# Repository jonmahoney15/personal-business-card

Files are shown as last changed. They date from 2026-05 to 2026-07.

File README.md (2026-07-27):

# Personal Business Card

ESP32-C3 powered business card with a MAX7219 LED matrix displaying a Snake game.

## Firmware
The app is written in Rust. It makes use of `esp_hal` and the `MAX7219` crate.

The embassy framework is used as the runtime enabling async workflows.

## Hardware

| Component | Description |
|---|---|
| ESP32-C3 | Wi-Fi/BLE microcontroller running the firmware |
| MAX7219 | LED matrix driver IC |
| LED Matrix 8x8 | 64-LED display used for the Snake game |
| AMS1117 | 3.3V linear voltage regulator |
| USB-C | Power and programming interface |

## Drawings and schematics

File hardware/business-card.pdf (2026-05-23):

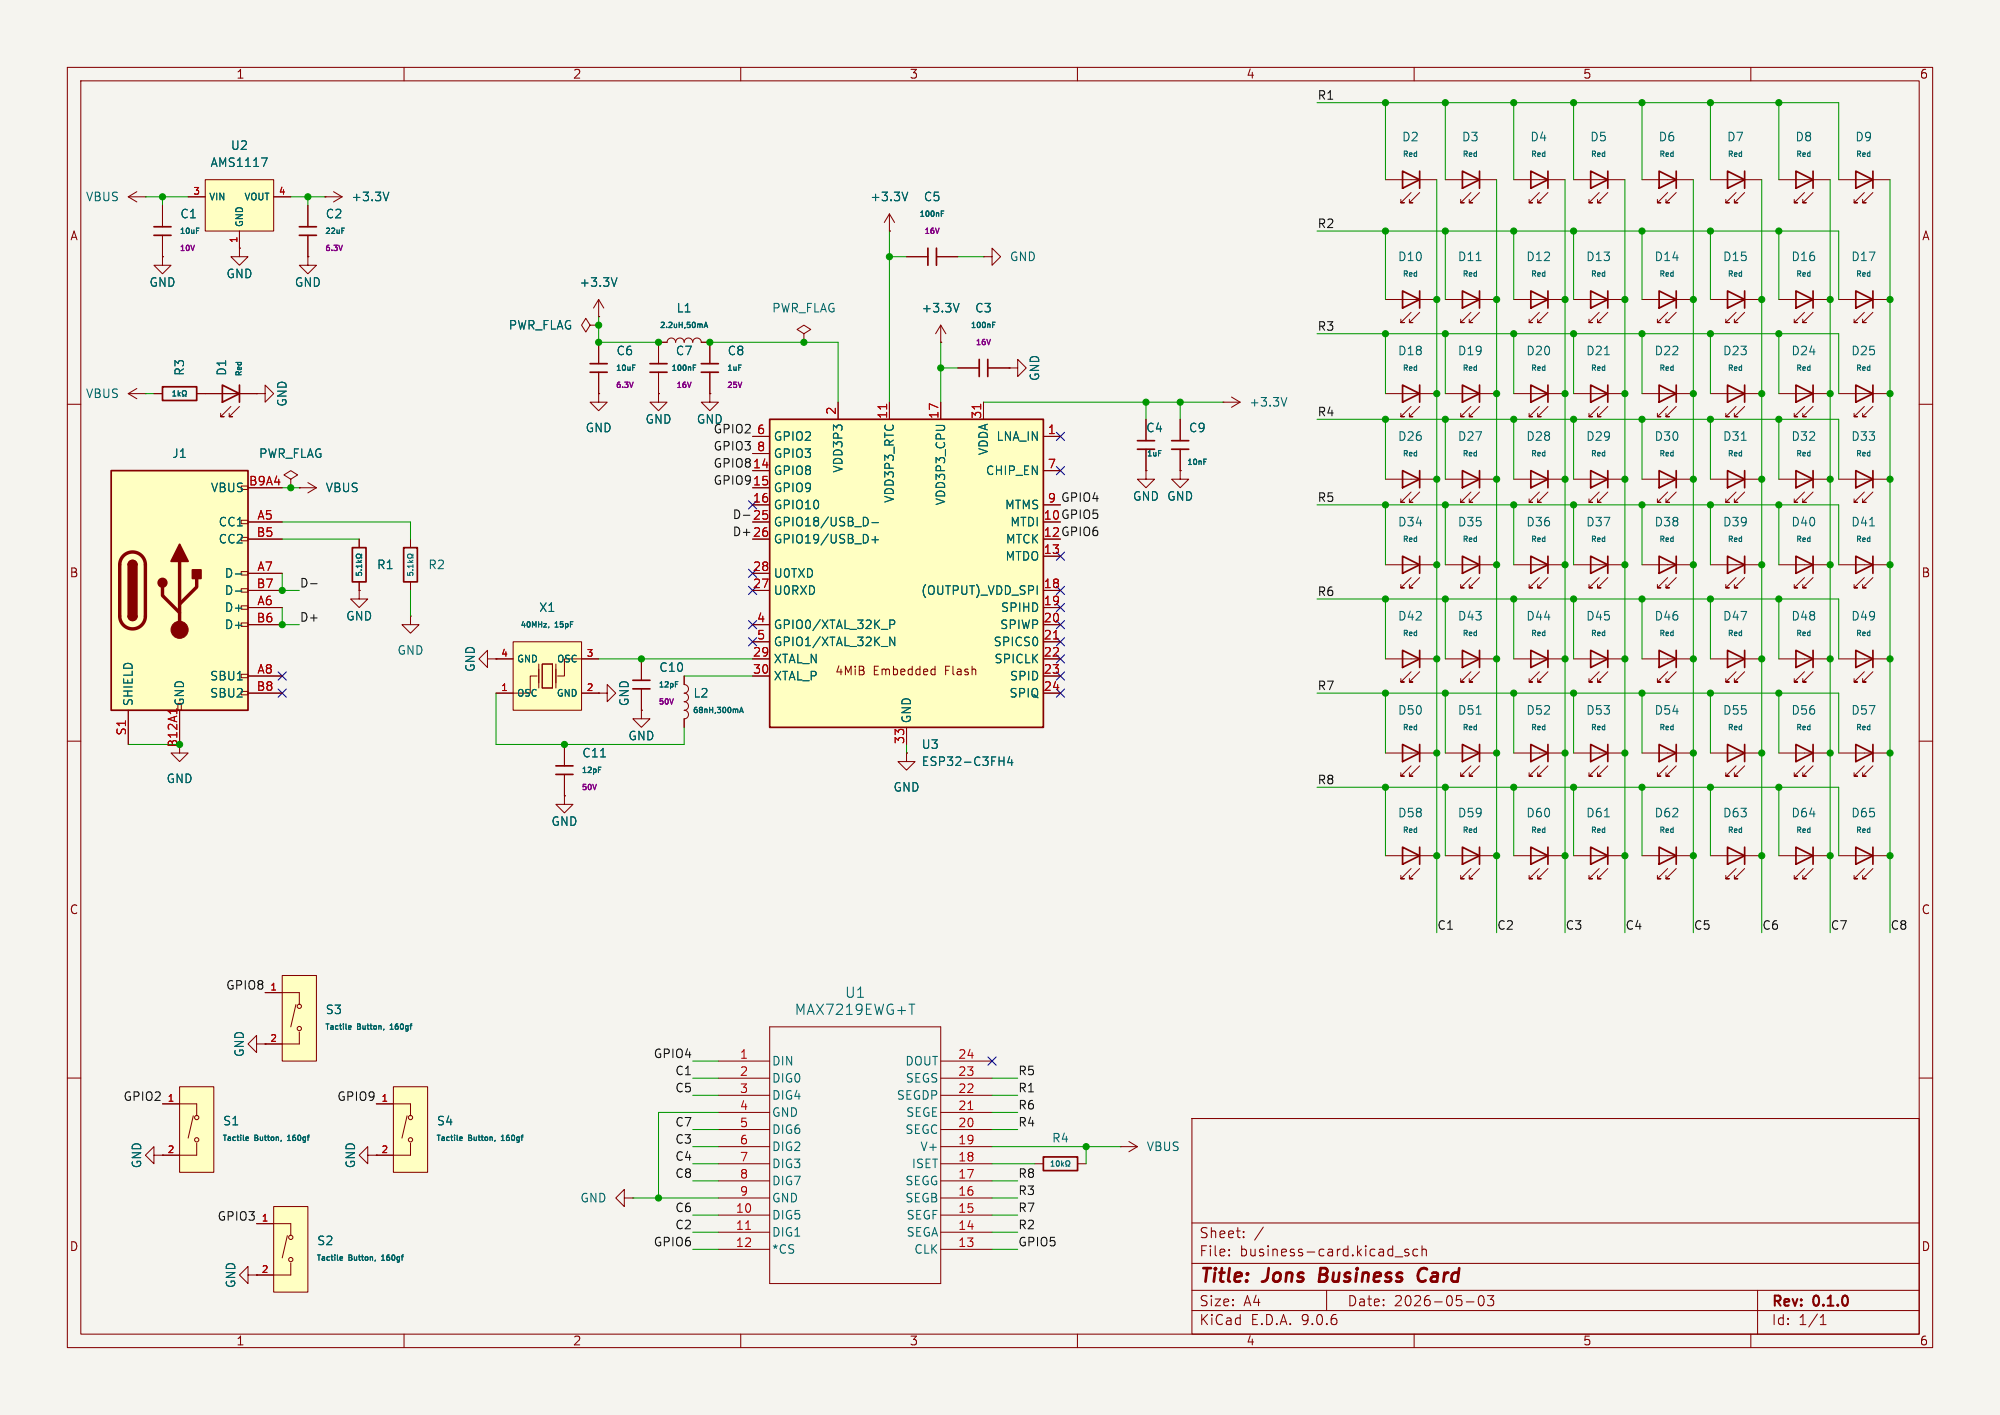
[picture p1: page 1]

Id: 1/1 Title: Jons Business Card

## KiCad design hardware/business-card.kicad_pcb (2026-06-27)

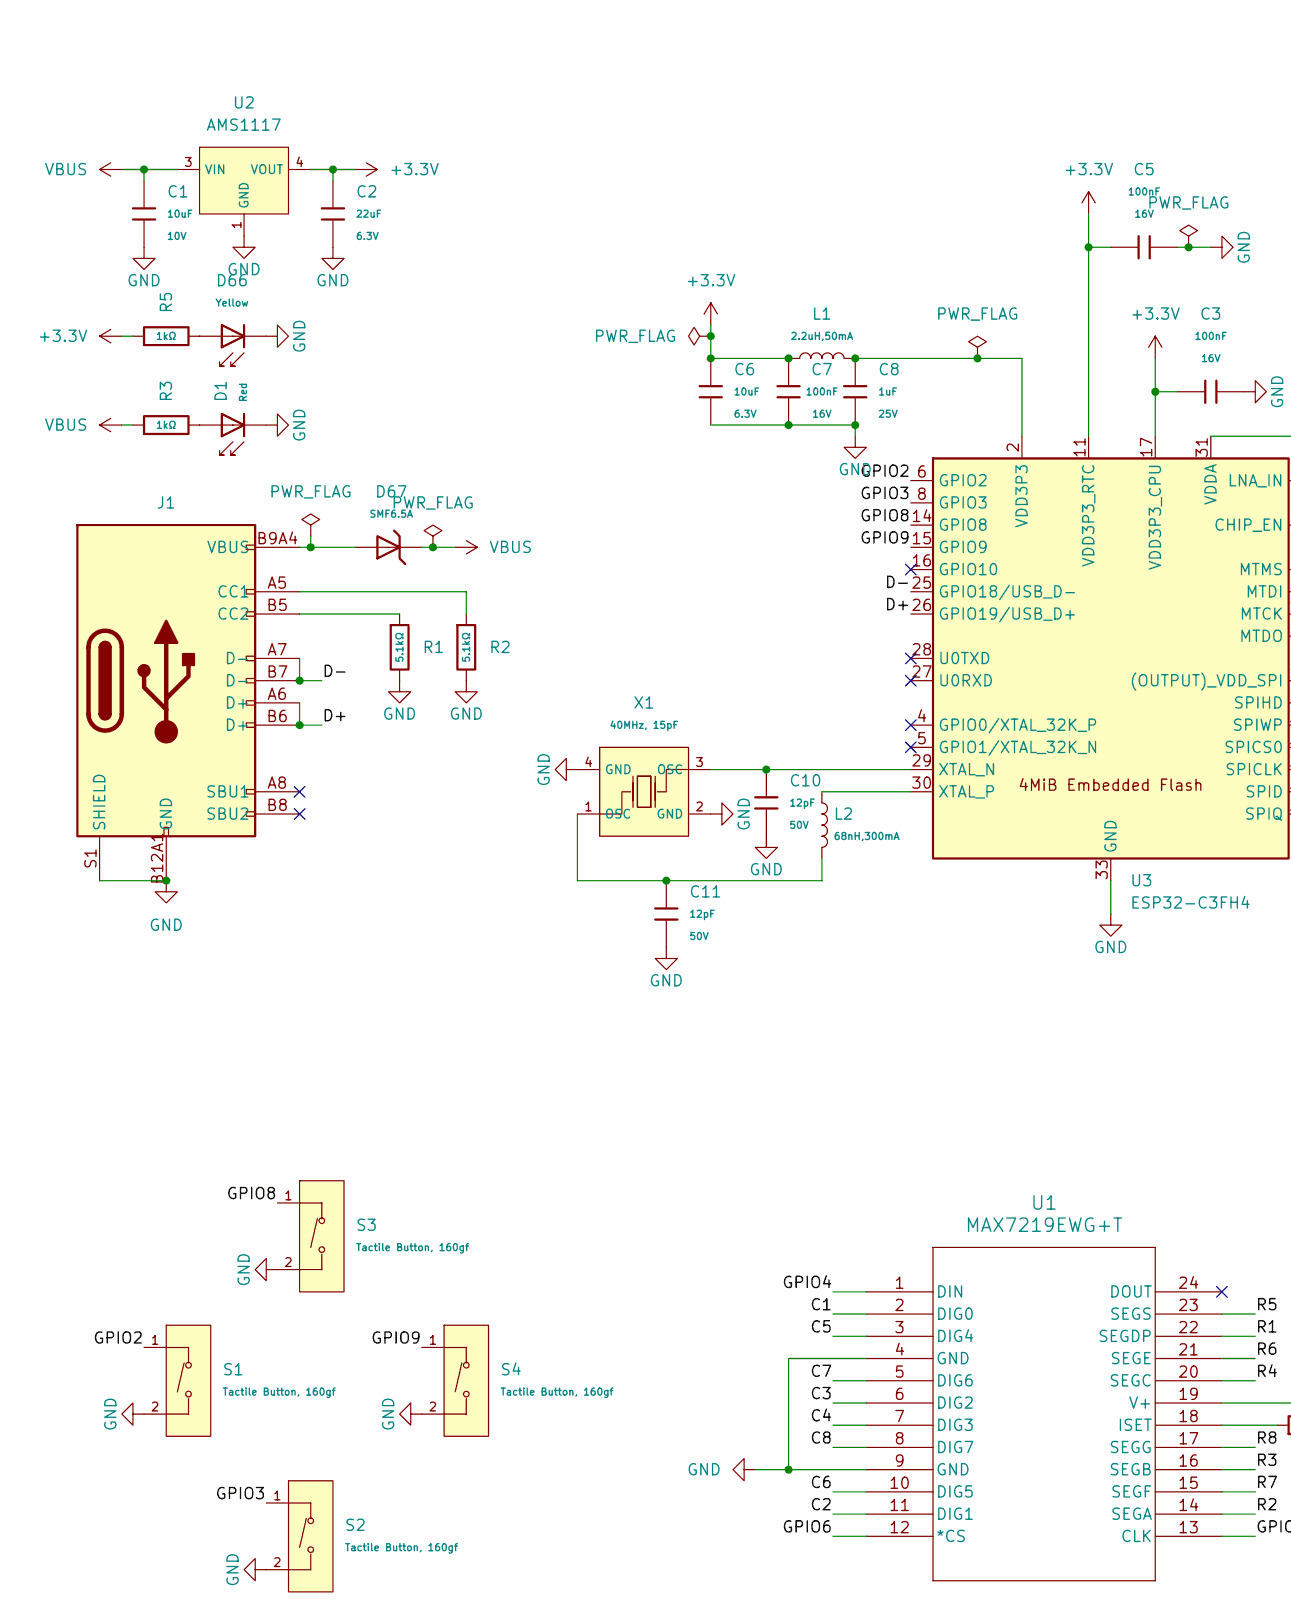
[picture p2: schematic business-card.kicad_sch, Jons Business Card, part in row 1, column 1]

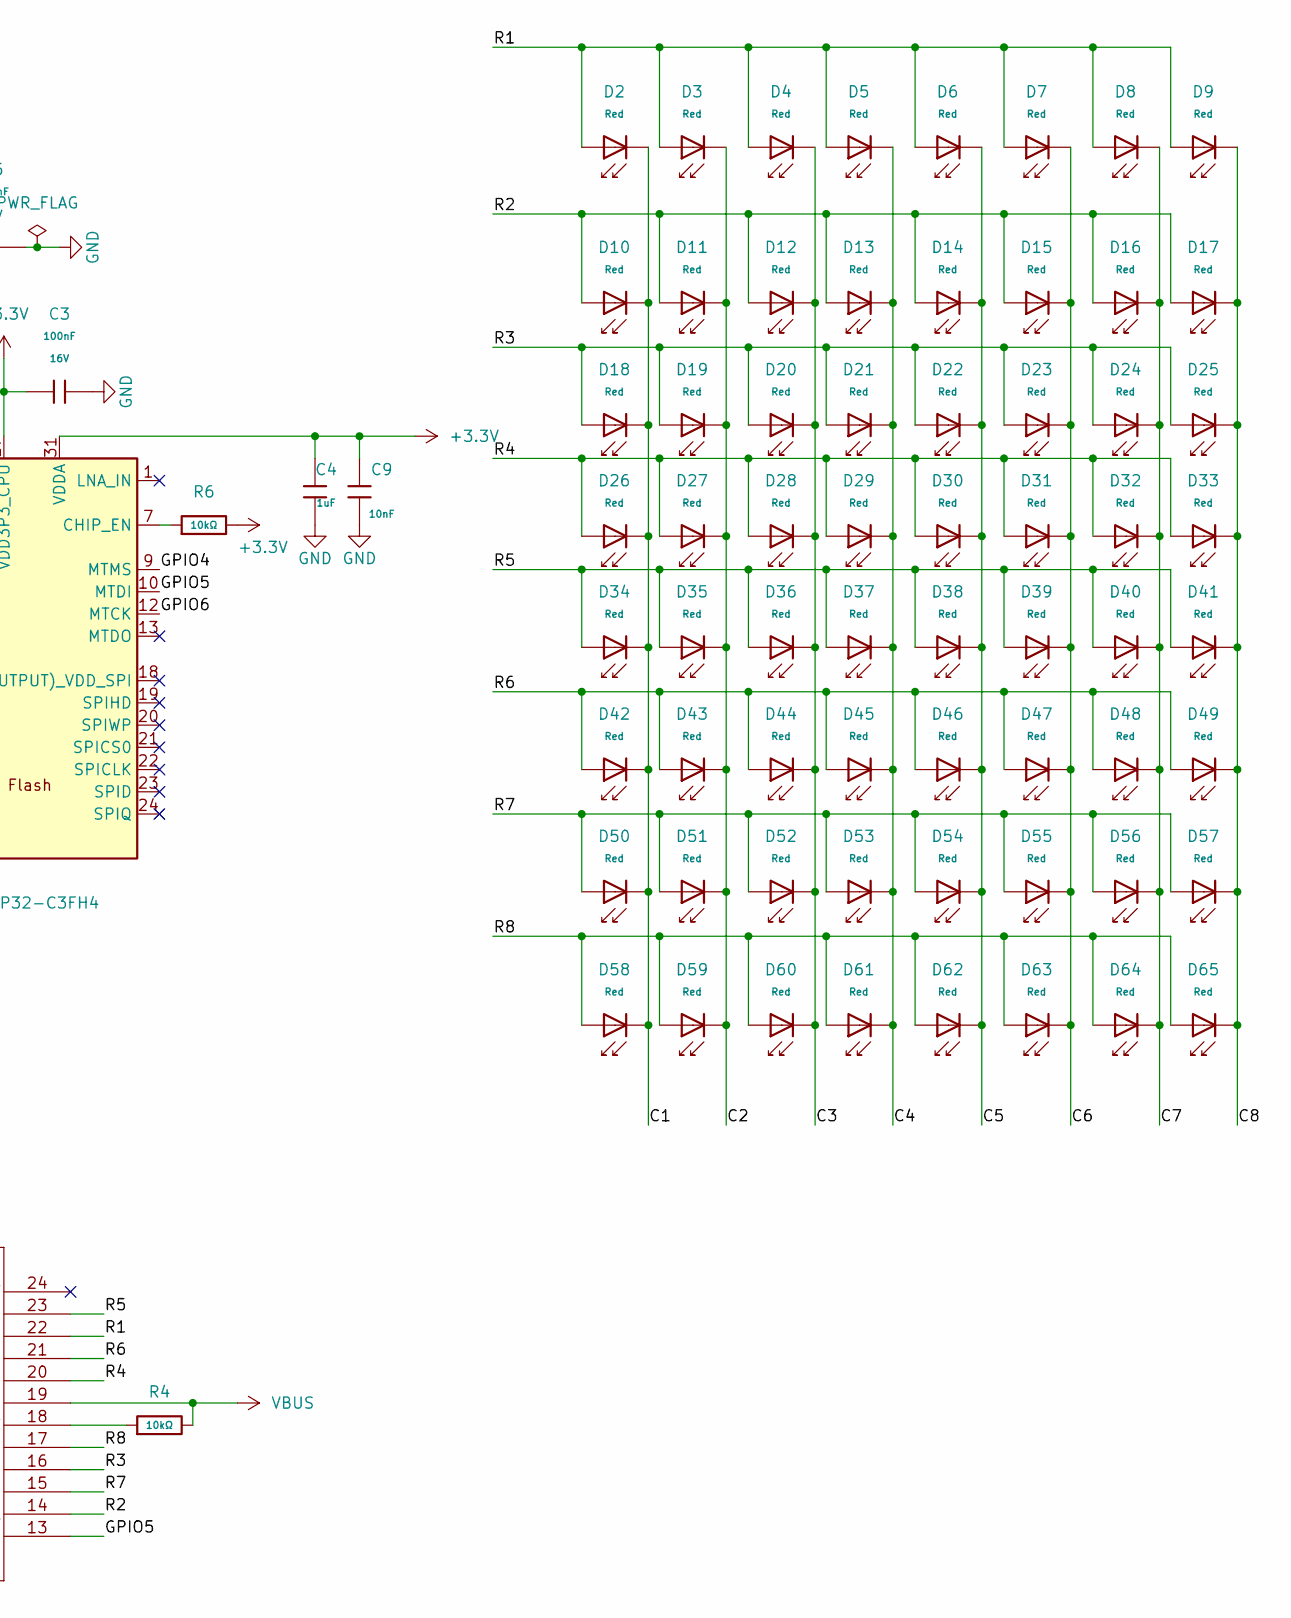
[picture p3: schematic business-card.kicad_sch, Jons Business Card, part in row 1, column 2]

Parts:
C1: 10uF; C_0603; Voltage Rated 10V; Tolerance ±10%; Part CL10A106KP8NNNC; LCSC C19702
C2: 22uF; C_0603; Voltage Rated 6.3V; Tolerance ±20%; Part CL10A226MQ8NRNC; LCSC C59461
C3, C5, C7: 100nF; C_0402; Voltage Rated 16V; Tolerance ±10%; Part CL05B104KO5NNNC; LCSC C1525
C4, C8: 1uF; C_0402; Voltage Rated 25V; Tolerance ±10%; Part CL05A105KA5NQNC; LCSC C52923
C6: 10uF; C_0402; Voltage Rated 6.3V; Tolerance ±20%; Part CL05A106MQ5NUNC; LCSC C15525
C9: 10nF; C_0402; Voltage Rated 50V; Tolerance ±10%; Part CL05B103KB5NNNC; LCSC C15195
C10, C11: 12pF; C_0402; Voltage Rated 50V; Tolerance ±5%; Part 0402CG120J500NT; LCSC C1547
D1, D2, D3, D4, D5, D6, D7, D8, D9, D10, D11, D12, D13, D14, D15, D16, D17, D18, D19, D20, D21, D22, D23, D24, D25, D26, D27, D28, D29, D30, D31, D32, D33, D34, D35, D36, D37, D38, D39, D40, D41, D42, D43, D44, D45, D46, D47, D48, D49, D50, D51, D52, D53, D54, D55, D56, D57, D58, D59, D60, D61, D62, D63, D64, D65: Red; D_0603; Part KT-0603R; LCSC C2286
D66: Yellow; D_0603; Forward Voltage (VF) 1.6V~2.6V; Part NCD0603Y2; LCSC C89811
D67: SMF6.5A; D_SOD-123FL; Clamping Voltage 11.2V; Voltage - Breakdown 7.98V; Part SMF6.5A; LCSC C41376089
J1: Connector, USB-TYPE-C-16P; TYPE-C-SMD_HX-TYPE-C-16PIN; LCSC C2927039
L1: 2.2uH,50mA; L_0805; Tolerance ±10%; Part CMI201209U2R2KT; LCSC C1043
L2: 68nH,300mA; L_0603; Tolerance ±5%; Part SDCL1608C68NJTDF; LCSC C13415
R1, R2: 5.1kΩ; R_0402; Overload Voltage (Max) 50V; Tolerance ±1%; Part 0402WGF5101TCE; LCSC C25905
R3, R5: 1kΩ; R_0402; Overload Voltage (Max) 50V; Tolerance ±1%; Part 0402WGF1001TCE; LCSC C11702
R4, R6: 10kΩ; R_0402; Overload Voltage (Max) 50V; Tolerance ±1%; Part 0402WGF1002TCE; LCSC C25744
S1, S2, S3, S4: Tactile Button, 160gf; SW_TS-1088-AR02016; Voltage Rating (Dc) 12V; Part TS-1088-AR02016; LCSC C720477
U1: MAX7219EWG+T; 21-0042_W24&plus_1_MXM; LCSC C52476
U2: AMS1117; SOT-223-3_L6.5-W3.4-P2.30-LS7.0-BR; Output Voltage 3.3V; Dropout Voltage 1.3V@(800mA); Part AMS1117-3.3; LCSC C6186
U3: ESP32-C3FH4; QFN-32-1EP_5x5mm_P0.5mm_EP3.7x3.7mm_ThermalVias; LCSC C2858491
X1: 40MHz, 15pF; OSC-SMD_4P-L3.2-W2.5-BL_SIT8008BI; PartID X322540MPB4SI; LCSC C9010

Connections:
+3.3V: C2.1, C3.1, C4.1, C5.1, C6.1, C7.1, C9.1, L1.1, R5.1, R6.2, U2.2 (VOUT), U2.4 (VOUT), U3.11 (VDD3P3_RTC), U3.17 (VDD3P3_CPU), U3.31 (VDDA), U3.32 (VDDA)
/C1: D2.1, D10.1, D18.1, D26.1, D34.1, D42.1, D50.1, D58.1, U1.2 (DIG0)
/C2: D3.1, D11.1, D19.1, D27.1, D35.1, D43.1, D51.1, D59.1, U1.11 (DIG1)
/C3: D4.1, D12.1, D20.1, D28.1, D36.1, D44.1, D52.1, D60.1, U1.6 (DIG2)
/C4: D5.1, D13.1, D21.1, D29.1, D37.1, D45.1, D53.1, D61.1, U1.7 (DIG3)
/C5: D6.1, D14.1, D22.1, D30.1, D38.1, D46.1, D54.1, D62.1, U1.3 (DIG4)
/C6: D7.1, D15.1, D23.1, D31.1, D39.1, D47.1, D55.1, D63.1, U1.10 (DIG5)
/C7: D8.1, D16.1, D24.1, D32.1, D40.1, D48.1, D56.1, D64.1, U1.5 (DIG6)
/C8: D9.1, D17.1, D25.1, D33.1, D41.1, D49.1, D57.1, D65.1, U1.8 (DIG7)
/D+: J1.A6 (D+), J1.B6 (D+), U3.26 (GPIO19/USB_D+)
/D-: J1.A7 (D-), J1.B7 (D-), U3.25 (GPIO18/USB_D-)
/GPIO2: S1.1 (A), U3.6 (GPIO2)
/GPIO3: S2.1 (A), U3.8 (GPIO3)
/GPIO4: U1.1 (DIN), U3.9 (MTMS)
/GPIO5: U1.13 (CLK), U3.10 (MTDI)
/GPIO6: U1.12 (*CS), U3.12 (MTCK)
/GPIO8: S3.1 (A), U3.14 (GPIO8)
/GPIO9: S4.1 (A), U3.15 (GPIO9)
/R1: D2.2, D3.2, D4.2, D5.2, D6.2, D7.2, D8.2, D9.2, U1.22 (SEGDP)
/R2: D10.2, D11.2, D12.2, D13.2, D14.2, D15.2, D16.2, D17.2, U1.14 (SEGA)
/R3: D18.2, D19.2, D20.2, D21.2, D22.2, D23.2, D24.2, D25.2, U1.16 (SEGB)
/R4: D26.2, D27.2, D28.2, D29.2, D30.2, D31.2, D32.2, D33.2, U1.20 (SEGC)
/R5: D34.2, D35.2, D36.2, D37.2, D38.2, D39.2, D40.2, D41.2, U1.23 (SEGS)
/R6: D42.2, D43.2, D44.2, D45.2, D46.2, D47.2, D48.2, D49.2, U1.21 (SEGE)
/R7: D50.2, D51.2, D52.2, D53.2, D54.2, D55.2, D56.2, D57.2, U1.15 (SEGF)
/R8: D58.2, D59.2, D60.2, D61.2, D62.2, D63.2, D64.2, D65.2, U1.17 (SEGG)
unnamed: C8.1, L1.2, U3.2 (VDD3P3), U3.3 (VDD3P3)
unnamed: C11.1, L2.2, X1.1 (OSC)
unnamed: D1.2, R3.2
unnamed: D66.2, R5.2
unnamed: D67.2, J1.A9B4 (VBUS), J1.B9A4 (VBUS)
unnamed: J1.A5 (CC1), R2.1
unnamed: J1.B5 (CC2), R1.1
unnamed: R4.1, U1.18 (ISET)
unnamed: R6.1, U3.7 (CHIP_EN)
unnamed: C10.1, U3.29 (XTAL_N), X1.3 (OSC)
unnamed: L2.1, U3.30 (XTAL_P)
VBUS: C1.1, D67.1, R3.1, R4.2, U1.19 (V+), U2.3 (VIN)

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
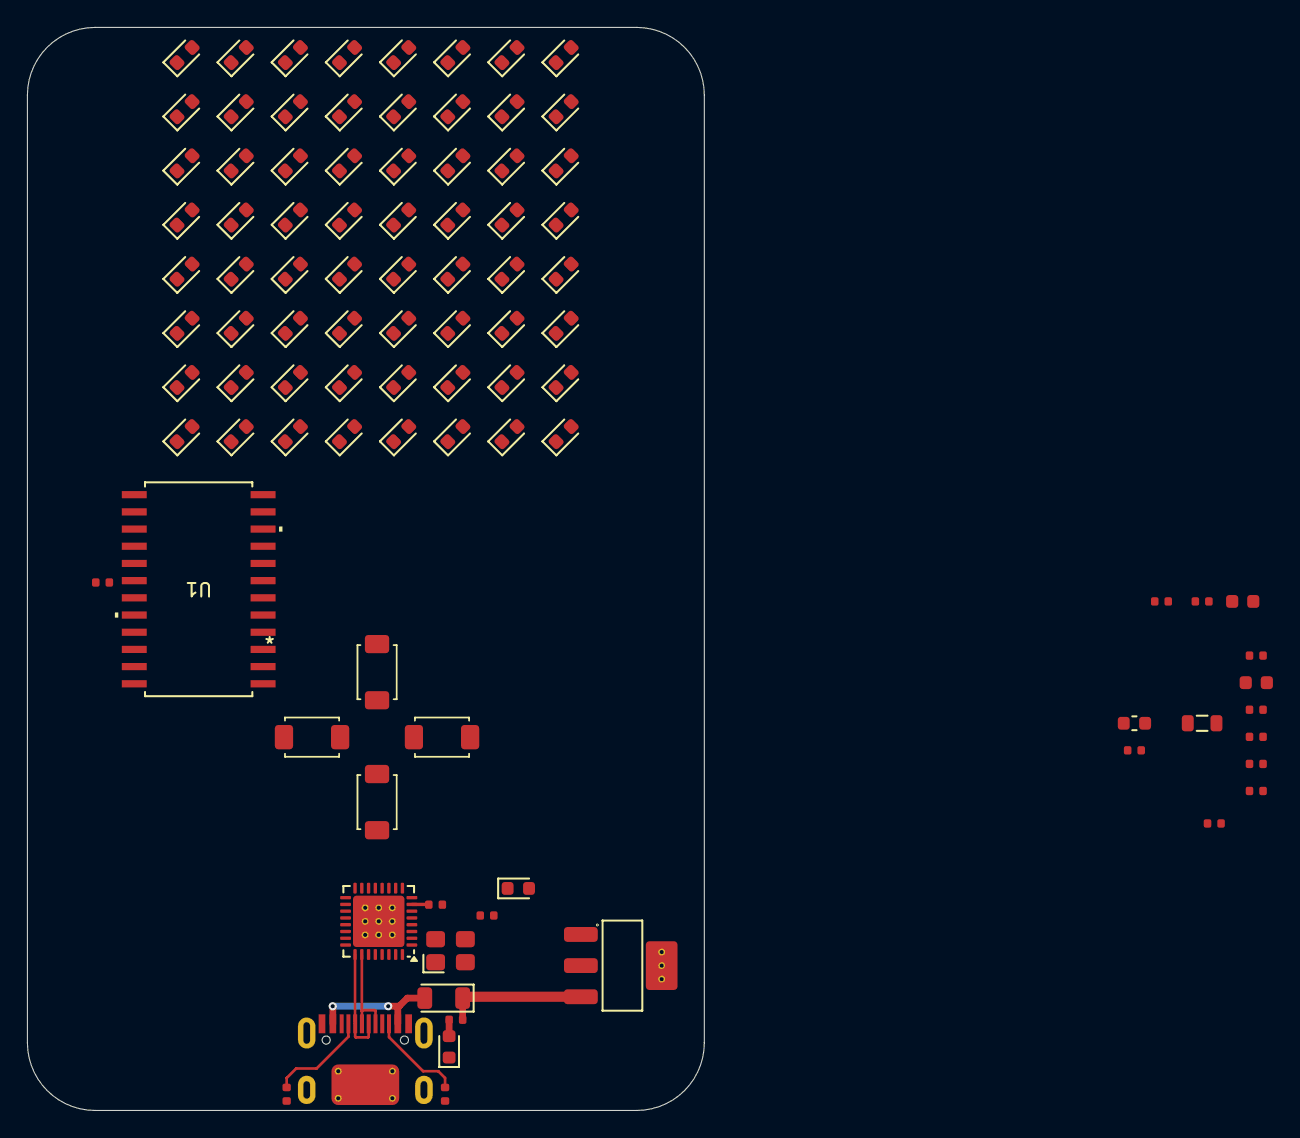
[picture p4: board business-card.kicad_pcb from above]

Board: 2 copper layers, 50.0 x 80.0 mm, 95 parts (0 on the bottom side), 39 nets.

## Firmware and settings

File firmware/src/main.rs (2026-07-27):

#![no_std]
#![no_main]
#![deny(
    clippy::mem_forget,
    reason = "mem::forget is generally not safe to do with esp_hal types, especially those \
    holding buffers for the duration of a data transfer."
)]
#![deny(clippy::large_stack_frames)]

mod display;
mod game;
mod snake;

use display::Display;
use embassy_executor::Spawner;
use embassy_sync::blocking_mutex::raw::CriticalSectionRawMutex;
use embassy_sync::channel::Channel;
use embassy_time::{Duration, Timer};
use esp_hal::clock::CpuClock;
use esp_hal::gpio::{AnyPin, Input, InputConfig, Pull};
use esp_hal::timer::timg::TimerGroup;
use game::Game;
use log::{debug, error};
use snake::Direction;
#[cfg(debug_assertions)]
use {
    embedded_io_async::Read,
    esp_hal::usb_serial_jtag::{UsbSerialJtag, UsbSerialJtagRx},
};

#[panic_handler]
fn panic(panic_info: &core::panic::PanicInfo) -> ! {
    error!("{}", panic_info);
    loop {}
}

esp_bootloader_esp_idf::esp_app_desc!();

static DIR_CHANNEL: Channel<CriticalSectionRawMutex, Direction, 8> = Channel::new();

#[allow(
    clippy::large_stack_frames,
    reason = "it's not unusual to allocate larger buffers etc. in main"
)]
#[esp_rtos::main]
async fn main(spawner: Spawner) -> ! {
    esp_println::logger::init_logger_from_env();

    let config = esp_hal::Config::default().with_cpu_clock(CpuClock::max());
    let peripherals = esp_hal::init(config);

    initialize_embassy(peripherals.TIMG0, peripherals.SW_INTERRUPT);

    let mut display = Display::init(
        peripherals.GPIO4.into(),
        peripherals.GPIO6.into(),
        peripherals.GPIO5.into(),
    );

    #[cfg(debug_assertions)]
    {
        let usb_serial = UsbSerialJtag::new(peripherals.USB_DEVICE).into_async();
        let (rx, _tx) = usb_serial.split();
        spawner.spawn(keyboard_input(rx).expect("spawn keyboard input"));
    }

    spawner.spawn(button(peripherals.GPIO8.into(), Direction::Up).expect("spawn up button"));
    spawner.spawn(button(peripherals.GPIO3.into(), Direction::Down).expect("spawn down button"));
    spawner.spawn(button(peripherals.GPIO2.into(), Direction::Left).expect("spawn left button"));
    spawner.spawn(button(peripherals.GPIO9.into(), Direction::Right).expect("spawn right button"));

    let mut game = Game::new();

    display.render(&game.frame());

    loop {
        if let Ok(direction) = DIR_CHANNEL.try_receive() {
            game.change_direction(direction);
        }

        game.tick();

        display.render(&game.frame());

        if !game.is_running() {
            debug!("Game over! Score: {}\r\n", game.score);
            display.show_score(game.score).await;
            display.toggle_screen_on_and_off().await;
            game.reset();
        }

        Timer::after(Duration::from_millis(300)).await;
    }
}

#[embassy_executor::task(pool_size = 4)]
async fn button(pin: AnyPin<'static>, dir: Direction) {
    let config = InputConfig::default().with_pull(Pull::Up);
    let btn = Input::new(pin, config);
    loop {
        if btn.is_low() {
            DIR_CHANNEL.send(dir).await;
            debug!("Button press {:?}\r", dir);
        }
        Timer::after(Duration::from_millis(100)).await;
    }
}

fn initialize_embassy(
    timg0: esp_hal::peripherals::TIMG0<'static>,
    sw_interrupt: esp_hal::peripherals::SW_INTERRUPT<'static>,
) {
    let timg0 = TimerGroup::new(timg0);
    let sw_interrupt = esp_hal::interrupt::software::SoftwareInterruptControl::new(sw_interrupt);
    esp_rtos::start(timg0.timer0, sw_interrupt.software_interrupt0);

    debug!("Embassy initialized!\r\n");
}

#[cfg(debug_assertions)]
#[embassy_executor::task]
async fn keyboard_input(mut rx: UsbSerialJtagRx<'static, esp_hal::Async>) {
    debug!("Keyboard input enabled (HJKL vim keys)\r\n");
    let mut buffer = [0u8; 1];
    loop {
        if let Ok(1) = rx.read(&mut buffer).await {
            let direction = match buffer[0] {
                b'h' | b'H' => Some(Direction::Left),
                b'j' | b'J' => Some(Direction::Down),
                b'k' | b'K' => Some(Direction::Up),
                b'l' | b'L' => Some(Direction::Right),
                _ => None,
            };

            if let Some(direction) = direction {
                DIR_CHANNEL.send(direction).await;
                debug!("Keyboard {:?}\r", direction);
            }
        }
    }
}

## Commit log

2026-05-17 Initialization of PCB Business Card Repo
    This repo will hold both the software and hardware that makes up the
    business card. I will also try to outline the steps I took in creating
    it so others can have fun designing one like I did.
    [business-card.kicad_pcb, business-card.kicad_sch]
2026-05-23 Added PDF of schematic
    Provided a schematic pdf to easily view when looking through repo.
    Created using:
    ```
    $ kicad-cli sch export pdf business-card.kicad_sch
    ```
2026-05-24 Update wokwi diagram to look like pcb
    The primary change was adding all 4 buttons.
2026-05-25 Initial LED Movement
2026-06-27 Add hardware gitignore
    - added gitignore for kicad
    - reformatted the rust code
2026-06-27 Add Kicad project to hardware
    Updated the hardware directory to hold the entire kicad project. Now the
    pcb can be developed on multiple kicad instances and maintained in git.
    [business-card.kicad_pcb, business-card.kicad_sch]
2026-07-27 Add Snake to business card
    Snake is a fun simple game to implement. This will allow a user to play
    snake when they plug in the pcb to a usbc.
    Removed the Max7219 impl for crate alternative.
2026-07-27 Update README with hardware table
    Hardware table added to describe the current major components used.
